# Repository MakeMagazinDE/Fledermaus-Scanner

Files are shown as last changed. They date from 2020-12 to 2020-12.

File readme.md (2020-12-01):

GitHub Logo

Maker Media GmbH
*** 

# Fledermaus-Scanner
Fledermausrufe mit dem Adafruit Feather M0 Basic Proto detektieren

### DIY-Projekt wandelt unhörbare Töne um

Mit einem MEMS-Mikrofon und einer kleinen Verstärkerschaltung lassen sich die hochfrequenten Töne von Fledermäusen in den Hörbereich des Menschen verschieben. Wer es lieber grafisch mag, kann die Töne über Processing auch als Spektrum anzeigen oder über einen Raspberry Pi an ein Node-RED-Dashboard senden.

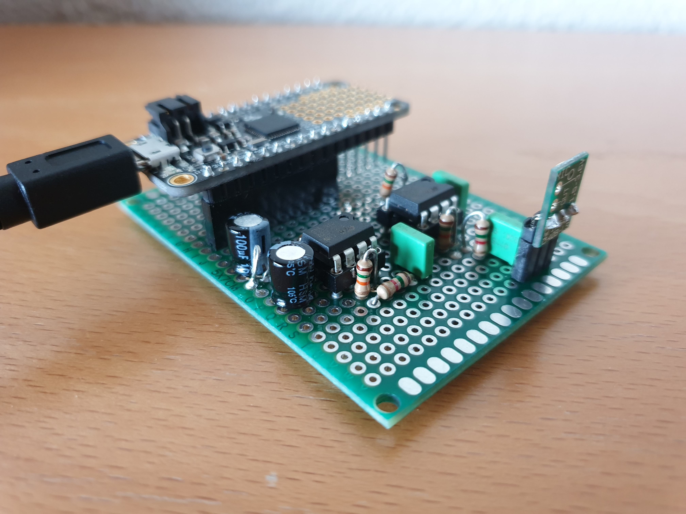
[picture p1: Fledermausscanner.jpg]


Den vollständigen Artikel mit der Bauanleitung gibt es in der [Make-Ausgabe 6/2020](https://www.heise.de/select/make/2020/6/seite-72) zu lesen.

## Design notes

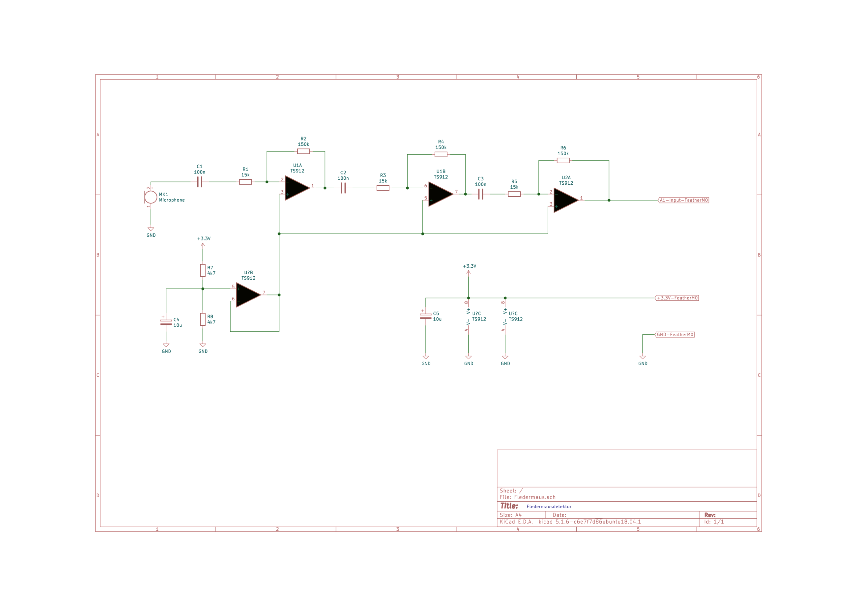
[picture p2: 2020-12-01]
Schaltplan KiCAD/Fledermaus_Schaltplan.png

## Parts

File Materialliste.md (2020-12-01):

# Fledermaus-Scanner

## Materialliste
- [ ] 1x  Adafruit Feather M0 Basic Proto (oder M0 Express)
- [ ] 1x  [ELV Komplettbausatz Mikrofon MEMS1](https://de.elv.com/elv-mikrofon-mems1-komplettbausatz-151456)
- [ ] 2x  Dual Rail-to-Rail Operationsverstärker TS912
- [ ] 3x  Folienkondensator 100nF
- [ ] 2x  Elektrolytkondensator 10uF
- [ ] 3x  Widerstand 150kOhm
- [ ] 3x  Widerstand 15kOhm
- [ ] 2x  Widerstand 4.7kOhm
- [ ] 1x  Lochrasterplatine Kupferbeschichtet

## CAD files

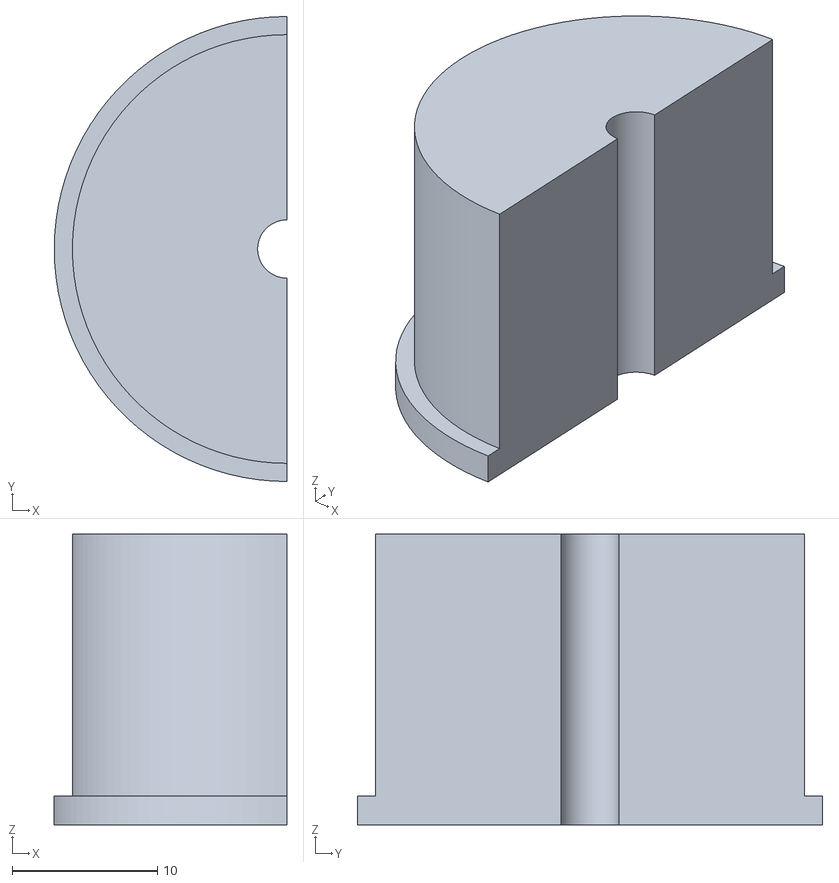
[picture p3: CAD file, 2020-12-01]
Druckdateien Gehäuse/Stopfen-Hinten.stl
16.0 x 32.0 x 20.0

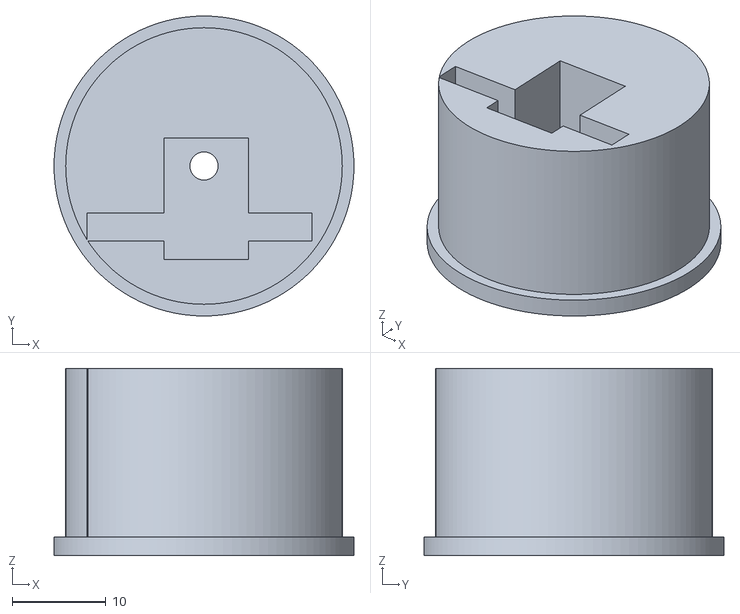
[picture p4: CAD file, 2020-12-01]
Druckdateien Gehäuse/Stopfen-Vorne.stl
32.0 x 32.0 x 20.0

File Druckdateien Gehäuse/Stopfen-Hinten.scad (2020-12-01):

$fn = 100;
difference() {
    union() {
        cylinder(r=29.5/2, h=20);
        cylinder(r=32/2, h=2);
    }
    translate([0,0,-1]) cylinder(r=2, h=30);
    translate([0,-20,-1]) cube([40,40,40]);
}

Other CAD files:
Druckdateien Gehäuse/Stopfen-Vorne.scad

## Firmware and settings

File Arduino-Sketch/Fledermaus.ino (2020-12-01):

/******************************************************************************************
 * Fledermausdetektor für den C-Turm      C-Hack/2020
 * 
 * Hardware: Feather M0 Proto Board mit ARM M0 und 350ksps ADC
 *           MEMS Mikrofon (ELV MEMS-1)  Knowles SPU0410LR5H 
 *           60dB Verstärkung mit TS912 Rail-to-Rail OpAmp
 *           
 * Software: ADC-DMA Funktionen (siehe unten)
 *           FFT Library
 *           
 * Return-Daten: Entweder detektierte Hochfrequenz (nur Frequenzangabe)
 *               Oder Roh FFT Daten
 *               Oder Roih Sampledaten
 *               
 ******************************************************************************************/
  int dataMode = '1';      // 0 = raw, 1 = FFT, 2 = Frequenzen

/*===========================================================================================
 * Adafruit FFT Library für SAMD21xx Prozessoren (ARM M0)
 *===========================================================================================*/
 #include "Adafruit_ZeroFFT.h"

/*=========================================================================================== 
 *  ADCDMA
 *  
 * analog A1
 *   
 * Nach http://www.atmel.com/Images/Atmel-42258-ASF-Manual-SAM-D21_AP-Note_AT07627.pdf pg 73
 * Urheber: https://github.com/manitou48/ZERO/blob/master/adcdma.ino 
 * 
 * Sampling Rate = 500ksps
 * Bins: Bin[HWORD/2] = 250kHz;
 * Umrechnung von bin Nr auf Frequenz: f(binNr) = 250 / HWORDS * binNr    [in kHz]
 *==========================================================================================*/
 
#define ADCPIN A1            // ADC Input Pin
#define HWORDS 2048          // Anzahl der Samples
uint16_t adcbuf[HWORDS];     // Datenarray (16bit Daten)
int16_t signal[HWORDS];
float bin, maxBin;


typedef struct {
    uint16_t btctrl;
    uint16_t btcnt;
    uint32_t srcaddr;
    uint32_t dstaddr;
    uint32_t descaddr;
} dmacdescriptor ;
volatile dmacdescriptor wrb[12] __attribute__ ((aligned (16)));
dmacdescriptor descriptor_section[12] __attribute__ ((aligned (16)));
dmacdescriptor descriptor __attribute__ ((aligned (16)));


static uint32_t chnl = 0;  // DMA channel
volatile uint32_t dmadone;

void DMAC_Handler() {
    // interrupts DMAC_CHINTENCLR_TERR DMAC_CHINTENCLR_TCMPL DMAC_CHINTENCLR_SUSP
    uint8_t active_channel;

    // disable irqs ?
    __disable_irq();
    active_channel =  DMAC->INTPEND.reg & DMAC_INTPEND_ID_Msk; // get channel number
    DMAC->CHID.reg = DMAC_CHID_ID(active_channel);
    dmadone = DMAC->CHINTFLAG.reg;
    DMAC->CHINTFLAG.reg = DMAC_CHINTENCLR_TCMPL; // clear
    DMAC->CHINTFLAG.reg = DMAC_CHINTENCLR_TERR;
    DMAC->CHINTFLAG.reg = DMAC_CHINTENCLR_SUSP;
    __enable_irq();
}


void dma_init() {
    // probably on by default
    PM->AHBMASK.reg |= PM_AHBMASK_DMAC ;
    PM->APBBMASK.reg |= PM_APBBMASK_DMAC ;
    NVIC_EnableIRQ( DMAC_IRQn ) ;

    DMAC->BASEADDR.reg = (uint32_t)descriptor_section;
    DMAC->WRBADDR.reg = (uint32_t)wrb;
    DMAC->CTRL.reg = DMAC_CTRL_DMAENABLE | DMAC_CTRL_LVLEN(0xf);
}

void adc_dma(void *rxdata,  size_t hwords) {
    uint32_t temp_CHCTRLB_reg;

    DMAC->CHID.reg = DMAC_CHID_ID(chnl);
    DMAC->CHCTRLA.reg &= ~DMAC_CHCTRLA_ENABLE;
    DMAC->CHCTRLA.reg = DMAC_CHCTRLA_SWRST;
    DMAC->SWTRIGCTRL.reg &= (uint32_t)(~(1 << chnl));
    temp_CHCTRLB_reg = DMAC_CHCTRLB_LVL(0) |
      DMAC_CHCTRLB_TRIGSRC(ADC_DMAC_ID_RESRDY) | DMAC_CHCTRLB_TRIGACT_BEAT;
    DMAC->CHCTRLB.reg = temp_CHCTRLB_reg;
    DMAC->CHINTENSET.reg = DMAC_CHINTENSET_MASK ; // enable all 3 interrupts
    dmadone = 0;
    descriptor.descaddr = 0;
    descriptor.srcaddr = (uint32_t) &ADC->RESULT.reg;
    descriptor.btcnt =  hwords;
    descriptor.dstaddr = (uint32_t)rxdata + hwords*2;   // end address
    descriptor.btctrl =  DMAC_BTCTRL_BEATSIZE_HWORD | DMAC_BTCTRL_DSTINC | DMAC_BTCTRL_VALID;
    memcpy(&descriptor_section[chnl],&descriptor, sizeof(dmacdescriptor));

    // start channel
    DMAC->CHID.reg = DMAC_CHID_ID(chnl);
    DMAC->CHCTRLA.reg |= DMAC_CHCTRLA_ENABLE;
}

static __inline__ void ADCsync() __attribute__((always_inline, unused));
static void   ADCsync() {
  while (ADC->STATUS.bit.SYNCBUSY == 1); //Just wait till the ADC is free
}


void adc_init(){
  analogRead(ADCPIN);  // do some pin init  pinPeripheral()
  ADC->CTRLA.bit.ENABLE = 0x00;             // Disable ADC
  ADCsync();
  //ADC->REFCTRL.bit.REFSEL = ADC_REFCTRL_REFSEL_INTVCC0_Val; //  2.2297 V Supply VDDANA
  //ADC->INPUTCTRL.bit.GAIN = ADC_INPUTCTRL_GAIN_1X_Val;      // Gain select as 1X
  ADC->INPUTCTRL.bit.GAIN = ADC_INPUTCTRL_GAIN_DIV2_Val;  // default
  ADC->REFCTRL.bit.REFSEL = ADC_REFCTRL_REFSEL_INTVCC1_Val;
  ADCsync();    //  ref 31.6.16
  ADC->INPUTCTRL.bit.MUXPOS = g_APinDescription[ADCPIN].ulADCChannelNumber;
  ADCsync();
  ADC->AVGCTRL.reg = 0x00 ;       //no averaging
  ADC->SAMPCTRL.reg = 0x00;  ; //sample length in 1/2 CLK_ADC cycles
  ADCsync();
  ADC->CTRLB.reg = ADC_CTRLB_PRESCALER_DIV16 | ADC_CTRLB_FREERUN | ADC_CTRLB_RESSEL_10BIT;
  ADCsync();
  ADC->CTRLA.bit.ENABLE = 0x01;
  ADCsync();
}



void setup(){
  int timeout;
  Serial.begin(115200);
  analogWriteResolution(10);
  analogWrite(A0,64);   // test with DAC 
  pinMode(LED_BUILTIN, OUTPUT);
  adc_init();
  dma_init();

  while (1==1) {
    timeout = 2000;
    
    if (Serial.available()) dataMode = Serial.read();
  
    digitalWrite(LED_BUILTIN, HIGH);
    adc_dma(adcbuf,HWORDS);           // Start des Samplings
    while((!dmadone) && (timeout>0)) {   // Warten, bis Sampling und DMA fertig (timeout notwendig)
      delay(1);
      timeout--;                  // Warten, bis Sampling und DMA fertig
    }
    digitalWrite(LED_BUILTIN, LOW);

    for (int i=0; i<HWORDS; i++) {    // Schreiben der Samples
      if (dataMode == '0') Serial.println(adcbuf[i]);
    }
 
    for (int i=0; i<HWORDS; i++) signal[i] = adcbuf[i]-512;     // DC Wert abziehen

    ZeroFFT(signal, HWORDS);          // FFT rechnen 
    for (int i=0; i<HWORDS/2; i++) {  // Schreiben der FFT Bins
      if (dataMode == '1') Serial.println(signal[i]);
    }
    if (dataMode == '1') Serial.println(32000);
    
    if (dataMode == '2') {
      Serial.print("Echo bei ");
      for (int i=0; i<HWORDS/2; i++) {
        if (signal[i]>10) {
          bin = i;
          maxBin = HWORDS;
          Serial.print(250000*bin/maxBin);
          Serial.print(" Hz, ");  
        }
      }
      Serial.println("."); 
    }
    delay(100);
  }
}


void loop() {
}

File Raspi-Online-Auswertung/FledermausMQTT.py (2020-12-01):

#!/usr/bin/python3

import serial
import paho.mqtt.client as mqtt #import the client1
broker_address="192.168.178.80"

print("creating new instance")
client = mqtt.Client("P1") #create new instance
print("connecting to broker")
client.connect(broker_address) #connect to broker


ser = serial.Serial('/dev/ttyACM0',115200)  # open serial port
print(ser.name)         # check which port was really used

out_array = {}
out_str = ""
send_array = {}
no_of_relevant_signals = 0;
idx = 0;

for i in range(0,32767):    # Prepare empty accumulation array of sufficient size
    send_array[i] = 0

while 1==1:

    value = str(ser.readline())              # read values from serial interface
    num_val = float(value[2:-5])
    if num_val<32000:                        # 32000 indicates that the whole FFT has been sent
        out_array[idx] = num_val
        idx = idx + 1

    if num_val == 32000:                     # Check if at least one of the FFT bins contains some signal
        signal_received = 0
        for i in range(0,len(out_array)-1):
            if out_array[i]>10:
                signal_received = 1;
                print(out_array[i]," at: ",i)

        if signal_received == 1:             # If one FFT bin contained a signal the whole dataset if printed and sent via MQTT
            no_of_relevant_signals = no_of_relevant_signals + 1         # Count those data setts which contain a signal of relevant strengths
            out_str = "[{\n \"series\": [\"C-Turm\"], \n\"data\": [ \n["
            for i in range(0,int(len(out_array)/2)):              # Only half of teh frequency range (up to 125kHz)
                if out_array[i] > send_array[i]:
                    send_array[i] = out_array[i]  # Accumulate OR Function
                out_str = out_str + "{ \"x\": "+ str(250000/1024*i) + ", \"y\": " + str(send_array[i]) + "},"   #  Divide by number of relevant signals captured

            out_str = out_str[0:-1] + "\n] \n], \n\"labels\": [\"\"] \n}]"    # Remove last Komma

            print(out_str);
            print("--------------------------------------------")

            client.publish("Fledermaus",out_str)                 # Here the whole FFT result is publish to MQTT

        idx=0;
        out_str = "";

        if no_of_relevant_signals>1000:           # Reset accumulated array after 1000 new relevant signals
            no_of_relevant_signals = 0;
            for i in range(0,len(send_array)):
                send_array[i]=0;

ser.close()             # close port - but this will never be reached because of the endless loop above
